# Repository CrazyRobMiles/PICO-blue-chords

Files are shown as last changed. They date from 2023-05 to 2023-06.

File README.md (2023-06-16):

# PICO-blue-chords

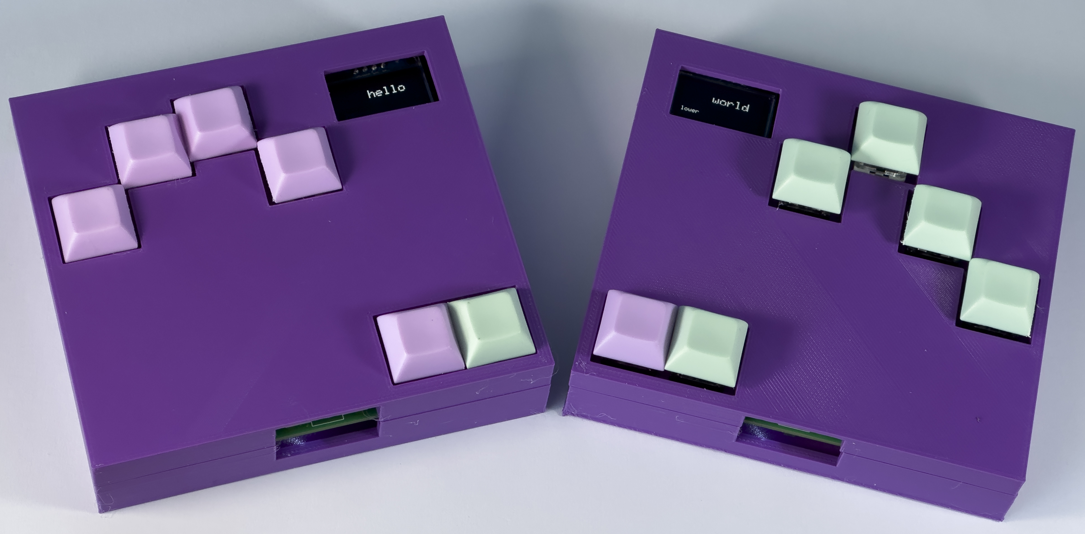
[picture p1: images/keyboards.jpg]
Image of left and right handed versions of the keyboard

This is a chord keyboard that uses the MicroWriter chord system. It uses the Bluetooth to connect and runs on a Raspberry Pi PICO-W. It is described in the HackSpace magazine. 
## Note
This is a work in progress. The software works correctly and the PCB and the case designs are now complete but these updated designs have not been constructed. The author knows of no reason why they won't work, but he didn't know of any reasons why the prototype wouldn't work until he tried to use it...

## Using a chord keyboard
You can find instructions on how to use the keyboard and the chord shapes in the doc folder. 
## Installing the software on your PICO from the UF2 Images
You can install the software by following these steps:
1. Press down the boot button on your PICO-W.
2. Connect your PICO-W to a usb port on your computer. 
3. The PICO-W should show up as a external drive.
4. The UF2 folder holds images for left and right handed use. Drag the left or right handed uf2 file onto the drive. 
5. The PICO-W will reboot running the software.
## Printed Circuit Board Designs
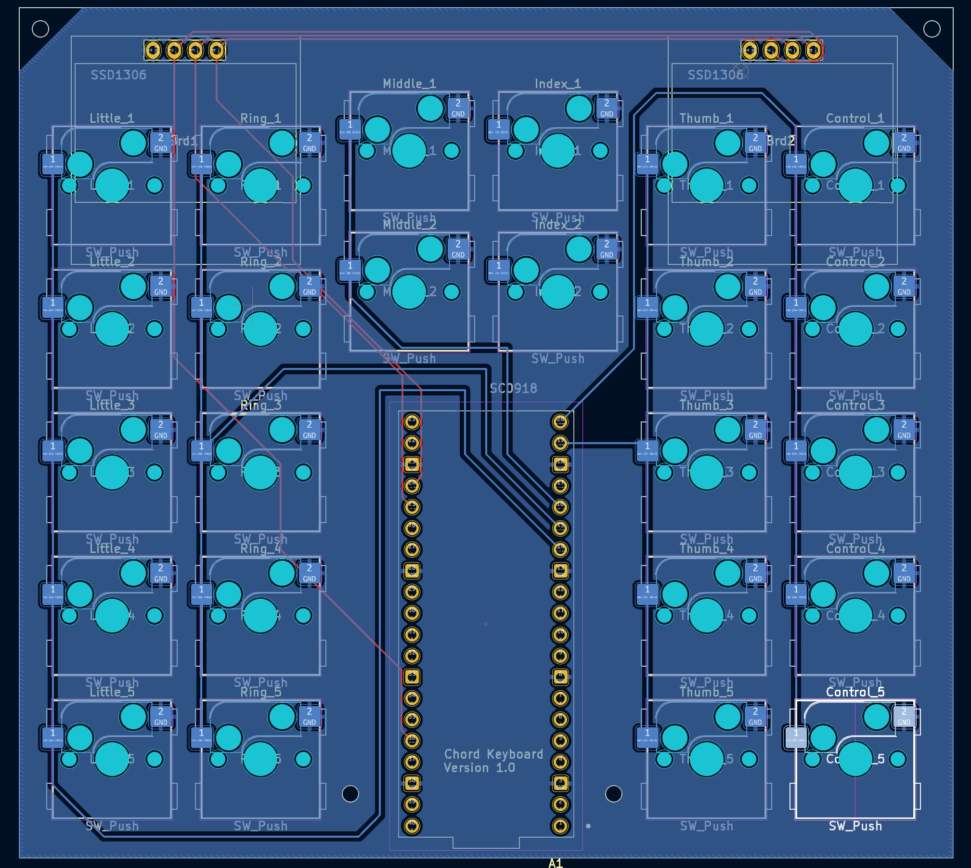
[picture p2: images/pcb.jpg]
Image of the keyboard PCB

The PCB designs are in the folder PICO-blue-chords-pcb. This folder also contains the partsdump.py file which can be used to extract the footprint positions for use in the case design software.
## Case 
To create a custom case design you use the PICO-blue-chords-case-builder.FCMacro macro which is in the cases folder. Load this into FreeCAD and select left or right handed and the specific key positions. The macro contains the following statements:
```
# right handed flag
right_handed = True 
if right_handed:
	keyHoles = [Little_5,Ring_5, Middle_2, Index_1, Thumb_1,Control_2]
	displayHole = Brd2
else:
      keyHoles = [Little_3,Ring_2, Middle_1, Index_2, Thumb_5,Control_5]
      displayHole = Brd1
```
Set the value of right_handed to False if you want a left-handed keyboard. Change the numbers for each key to match the position that you want for that key hole. The higher the number the farther down the keyboard the key hole will be placed. You can see the key numbers on the PCB design above. Run the macro and then export the resulting design as an STL file for printing. 
## Building the code
You use CMAKE to build the application from source. If you load the project with Visual Studio Code, make sure that you have the CMake Tools extension installed. The file CMakeLists.txt is used to create the makefiles for the build. Line 10 of this file sets the path to the SDK:
```
set(PICO_SDK_PATH "C:/Program Files/Raspberry Pi/Pico SDK v1.5.1/pico-sdk")
```
This works on my Windows system. You may need to change this when building the software on your machine. Note that you don't need to build the software yourself to use it. You can just install the image files which will be in the build folder which is created by the build process. 

## Origins
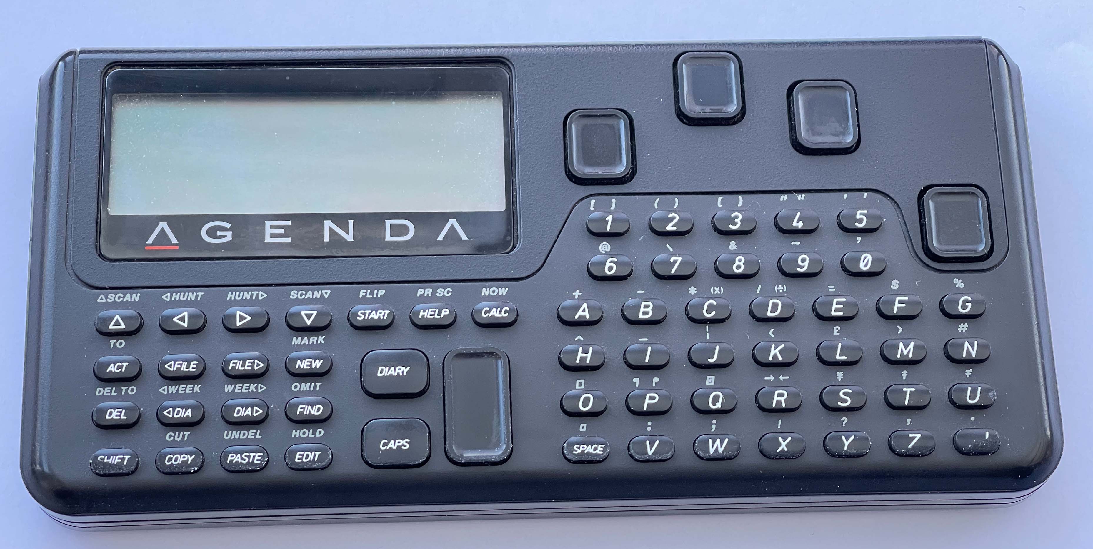
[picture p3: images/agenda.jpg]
Image of Microwriter Agenda

The keyboard is based on the Cykey chord design by Cy Enfield which was used as the basis of the Microwriter and Microwriter AgendA devices developed by him and Chris Rainey. You can find out more about these devices [here](http://www.computinghistory.org.uk/det/5794/Microwriter-MW4/), [here](https://www.microsoft.com/buxtoncollection/detail.aspx?id=5) and [here](https://mindmachine.co.uk/book/A/Inp-Outp/Microwriter01.html). 

If you want to buy an official Microwriter keyboard you can get one [here](https://sites.google.com/site/cykeybellaire/home). 

Have fun!

Rob Miles: [blog](https://www.robmiles.com)

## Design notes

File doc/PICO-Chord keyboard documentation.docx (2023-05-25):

The keyboard can be used in place of a Bluetooth keyboard. Before you use it you must pair it with your device. It will appear as the device “Blue Chord Keyboard xx:xx:xx:xx . You may need to re-pair it after it has been powered down.

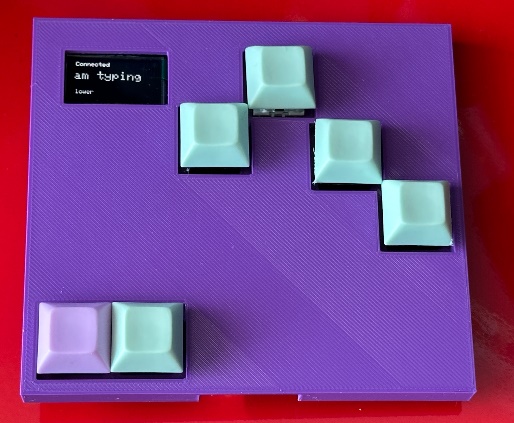
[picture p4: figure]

A right-handed version of the keyboard. The right hand five keys are used to enter chords. The left hand key is used as a control key.

# Typing Text

You type on the keyboard by pressing down "chords". A chord is one or more keys. A character is registered when you release one of the keys in the chord that describes it. Release all the chord keys for character before entering the next one. A map of all the chords is at the end of this document. Text is entered using the five keys underneath the hand shown on the left. The far-left key is the control key.

# Control Key

The control key is used to change the mode of the keyboard. You use it by moving your thumb slightly left to press that key. If you press and release just the control key the keyboard will change from lower case to upper case text entry. Press and release the control key again to return the lower-case text.

## Commands

The control key can be used in conjunction with other letters to enter commands that change the mode of the keyboard and send cursor control commands from the keyboard. The chords for the commands are given at the end of this document. There are three kinds of command. Cursor control, keyboard mode and keyboard functions.

## Cursor control

bak move the cursor left. This sends a keypress that moves the cursor one position left.

del backspace delete. This sends a keypress that deletes the character under the cursor and moves the cursor one space to the left.

## Keyboard mode

The keyboard mode is shown on the bottom of the display screen:

CAPS toggle the caps lock state by pressing the Control key on its own.

num enter numeric mode. The keys will turn green. You can enter numbers using the chords described in the Numbers section of the chord descriptions.

sym enter symbol mode. The keys will turn magenta. You can enter symbols using the chords described in the Symbols part of the chord descriptions.

lower enter lower case text mode. The keys will turn blue and the keyboard will be set to enter lower case text. You use this mode to exit from num or sym mode.

space

[ ] [ ] [ ] [ ]

[ ] [X]

,

[X] [ ] [X] [X]

[ ] [ ]

[X] [X] [X] [ ]

[ ] [ ]

A

[X] [X] [ ] [ ]

[ ] [ ]

B

[ ] [X] [X] [X]

[ ] [ ]

C

[ ] [X] [ ] [ ]

[ ] [X]

D

[X] [X] [ ] [ ]

[ ] [X]

E

[X] [ ] [ ] [ ]

[ ] [ ]

F

[X] [X] [X] [ ]

[ ] [X]

G

[ ] [ ] [X] [X]

[ ] [ ]

H

[ ] [ ] [ ] [X]

[ ] [X]

I

[X] [ ] [ ] [ ]

[ ] [X]

J

[ ] [ ] [X] [X]

[ ] [X]

K

[ ] [ ] [X] [ ]

[ ] [X]

L

[X] [ ] [ ] [X]

[ ] [X]

M

[X] [X] [X] [X]

[ ] [ ]

N

[ ] [X] [X] [ ]

[ ] [ ]

O

[ ] [X] [ ] [ ]

[ ] [ ]

P

[X] [X] [X] [X]

[ ] [X]

Q

[ ] [X] [ ] [X]

[ ] [ ]

R

[X] [ ] [X] [ ]

[ ] [X]

S

[ ] [ ] [X] [ ]

[ ] [ ]

T

[X] [ ] [X] [ ]

[ ] [ ]

U

[ ] [ ] [ ] [X]

[ ] [ ]

V

[X] [ ] [ ] [X]

[ ] [ ]

W

[X] [ ] [X] [X]

[ ] [X]

X

[ ] [X] [X] [X]

[ ] [X]

Y

[ ] [X] [X] [ ]

[ ] [X]

Z

[ ] [X] [ ] [X]

[ ] [X]

,

[X] [ ] [X] [X]

[ ] [ ]

[X] [X] [X] [ ]

[ ] [ ]

0

[ ] [X] [ ] [ ]

[ ] [ ]

1

[ ] [ ] [ ] [ ]

[ ] [X]

2

[X] [ ] [ ] [ ]

[ ] [X]

3

[X] [X] [ ] [ ]

[ ] [X]

4

[X] [X] [X] [ ]

[ ] [X]

5

[X] [X] [X] [X]

[ ] [X]

6

[ ] [ ] [ ] [X]

[ ] [ ]

7

[ ] [ ] [X] [X]

[ ] [ ]

8

[ ] [X] [X] [X]

[ ] [ ]

9

[X] [X] [X] [X]

[ ] [ ]

space

[ ] [ ] [ ] [ ]

[ ] [X]

!

[ ] [X] [X] [X]

[ ] [X]

[ ] [ ] [ ] [X]

[ ] [X]

$

[ ] [ ] [X] [ ]

[ ] [ ]

%

[ ] [X] [ ] [X]

[ ] [X]

&

[X] [ ] [X] [ ]

[ ] [X]

(

[X] [X] [ ] [ ]

[ ] [X]

)

[ ] [X] [X] [X]

[ ] [ ]

*

[X] [ ] [X] [ ]

[ ] [ ]

+

[X] [X] [X] [X]

[ ] [X]

,

[X] [ ] [X] [X]

[ ] [ ]

[ ] [X] [X] [ ]

[ ] [ ]

[X] [X] [X] [ ]

[ ] [ ]

/

[ ] [ ] [X] [ ]

[ ] [X]

:

[X] [ ] [X] [X]

[ ] [X]

;

[ ] [ ] [X] [X]

[ ] [X]

<

[X] [ ] [ ] [ ]

[ ] [X]

=

[X] [ ] [ ] [ ]

[ ] [ ]

>

[ ] [ ] [X] [X]

[ ] [ ]

?

[ ] [X] [X] [ ]

[ ] [X]

@

[X] [X] [ ] [ ]

[ ] [ ]

[

[ ] [X] [ ] [ ]

[ ] [X]

\

[X] [ ] [ ] [X]

[ ] [ ]

]

[ ] [X] [ ] [X]

[ ] [ ]

{

[X] [X] [X] [ ]

[ ] [X]

}

[X] [X] [X] [X]

[ ] [ ]

# Cursor

bak : Cursor left

[ ] [X] [X] [X]

[X] [ ]

del : Backspace

[X] [X] [ ] [ ]

[X] [ ]

# Mode

cap : CAPS

[ ] [ ] [ ] [ ]

[X] [ ]

num : Numeric

[ ] [X] [X] [ ]

[X] [ ]

sym : Symbol

[ ] [ ] [X] [ ]

[X] [ ]

text : lower

[X] [ ] [X] [ ]

[X] [ ]

Rob Miles Version 1.0 May 2023

https://github.com/CrazyRobMiles/PICO-blue-chords

PICO Blue Chords Keyboard

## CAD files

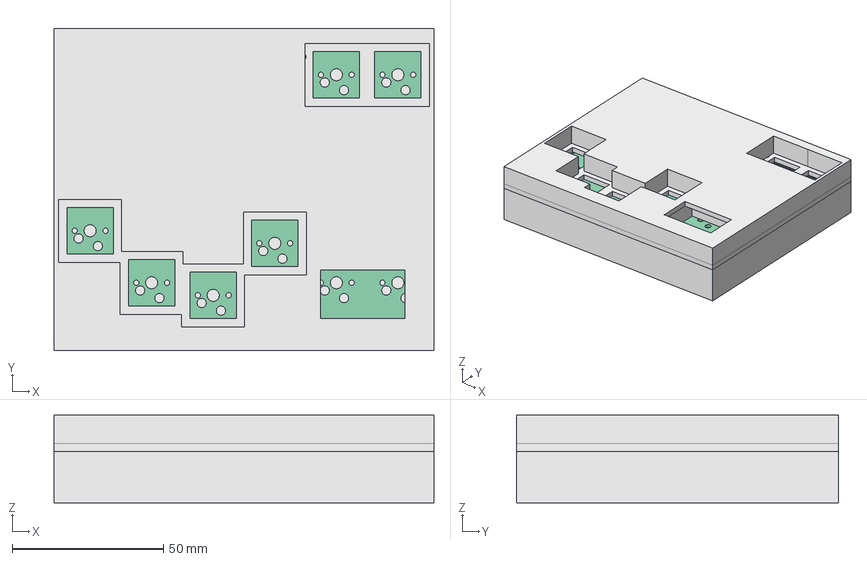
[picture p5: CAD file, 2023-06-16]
case/PCB and case.FCStd
125.5 x 106.5 x 28.9 mm
Pcb_e212

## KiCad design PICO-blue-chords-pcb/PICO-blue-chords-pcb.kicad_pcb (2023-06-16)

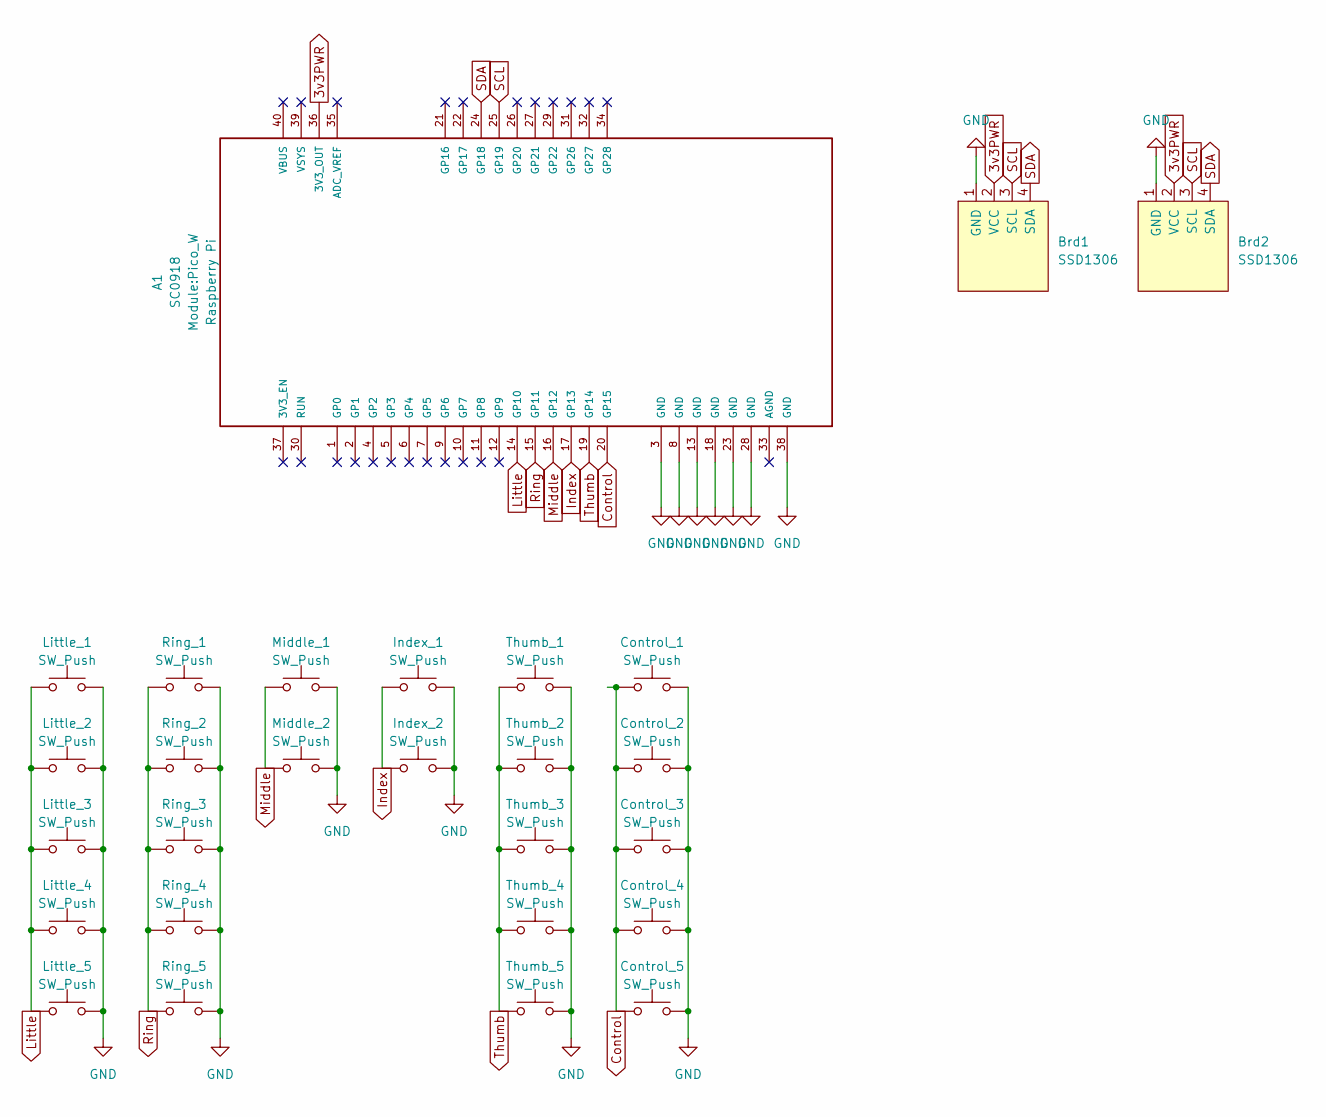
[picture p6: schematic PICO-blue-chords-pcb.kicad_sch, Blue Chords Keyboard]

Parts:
A1: SC0918; Pico_W; PARTREV 1.6
Brd1, Brd2: SSD1306; 128x64OLED
Control_1, Control_2, Control_3, Control_4, Control_5: SW_Push; SW_Hotswap_Kailh_MX
Index_1, Index_2: SW_Push; SW_Hotswap_Kailh_MX
Little_1, Little_2, Little_3, Little_4, Little_5: SW_Push; SW_Hotswap_Kailh_MX
Middle_1, Middle_2: SW_Push; SW_Hotswap_Kailh_MX
Ring_1, Ring_2, Ring_3, Ring_4, Ring_5: SW_Push; SW_Hotswap_Kailh_MX
Thumb_1, Thumb_2, Thumb_3, Thumb_4, Thumb_5: SW_Push; SW_Hotswap_Kailh_MX

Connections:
3v3PWR: A1.36 (3V3_OUT), Brd1.2 (VCC), Brd2.2 (VCC)
Control: A1.20 (GP15), Control_1.1, Control_2.1, Control_3.1, Control_4.1, Control_5.1
GND: A1.3 (GND), A1.8 (GND), A1.13 (GND), A1.18 (GND), A1.23 (GND), A1.28 (GND), A1.38 (GND), Brd1.1 (GND), Brd2.1 (GND), Control_1.2, Control_2.2, Control_3.2, Control_4.2, Control_5.2, Index_1.2, Index_2.2, Little_1.2, Little_2.2, Little_3.2, Little_4.2, Little_5.2, Middle_1.2, Middle_2.2, Ring_1.2, Ring_2.2, Ring_3.2, Ring_4.2, Ring_5.2, Thumb_1.2, Thumb_2.2, Thumb_3.2, Thumb_4.2, Thumb_5.2
Index: A1.17 (GP13), Index_1.1, Index_2.1
Little: A1.14 (GP10), Little_1.1, Little_2.1, Little_3.1, Little_4.1, Little_5.1
Middle: A1.16 (GP12), Middle_1.1, Middle_2.1
Ring: A1.15 (GP11), Ring_1.1, Ring_2.1, Ring_3.1, Ring_4.1, Ring_5.1
SCL: A1.25 (GP19), Brd1.3 (SCL), Brd2.3 (SCL)
SDA: A1.24 (GP18), Brd1.4 (SDA), Brd2.4 (SDA)
Thumb: A1.19 (GP14), Thumb_1.1, Thumb_2.1, Thumb_3.1, Thumb_4.1, Thumb_5.1

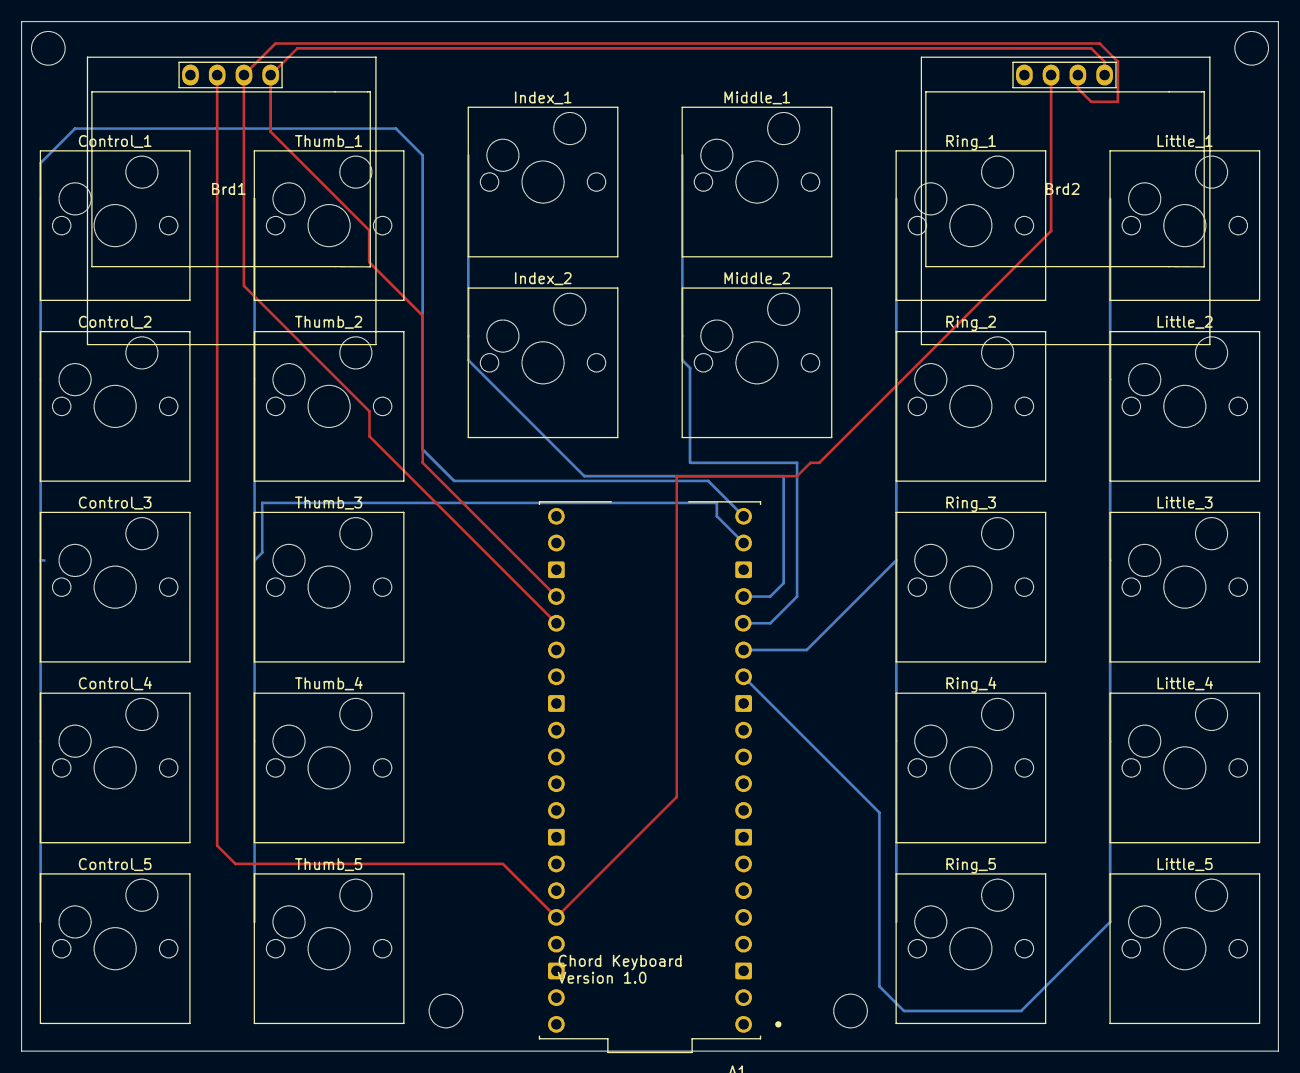
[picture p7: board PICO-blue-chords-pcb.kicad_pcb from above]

Board: 2 copper layers, 119.4 x 97.8 mm, 27 parts (0 on the bottom side), 10 nets.

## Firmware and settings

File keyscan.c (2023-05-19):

#include <stdio.h>
#include "pico/stdlib.h"
#include "hardware/gpio.h"
#include "messages.h"
#include "keyscan.h"

#ifdef LEFT_HANDED_KEYBOARD

#define LITTLE_KEY_GPIO 15
#define RING_KEY_GPIO 14
#define MIDDLE_KEY_GPIO 13
#define INDEX_KEY_GPIO 12
#define THUMB_KEY_GPIO 11
#define CONTROL_KEY_GPIO 10

#else

#define LITTLE_KEY_GPIO 10
#define RING_KEY_GPIO 11
#define MIDDLE_KEY_GPIO 12
#define INDEX_KEY_GPIO 13
#define THUMB_KEY_GPIO 14
#define CONTROL_KEY_GPIO 15

#endif

enum keyboard_states
{
    UPPER_CASE_KEYS,
    LOWER_CASE_KEYS,
    NUMBER_KEYS,
    SYMBOL_KEYS
};

enum keyboard_states keyboard_state;

struct key
{
    int gpio;
    bool state;
    char *name;
    int change_counter;
    int bit_number;
};

struct key keys[] =
    {
        {LITTLE_KEY_GPIO, false, "little key", 0, 0},
        {RING_KEY_GPIO, false, "ring key", 0, 1},
        {MIDDLE_KEY_GPIO, false, "middle key", 0, 2},
        {INDEX_KEY_GPIO, false, "index key", 0, 3},
        {THUMB_KEY_GPIO, false, "thumb", 0, 4},
        {CONTROL_KEY_GPIO, false, "control", 0, 5}};

#define DEBOUNCE_COUNT 1
#define KEY_PRESSED false

struct key_decode
{
    int scan;
    char ch;
};

struct key_decode lower_case_text_decode[] = {
    {12, 'a'},
    {56, 'b'},
    {10, 'c'},
    {14, 'd'},
    {4, 'e'},
    {30, 'f'},
    {48, 'g'},
    {34, 'h'},
    {6, 'i'},
    {50, 'j'},
    {18, 'k'},
    {38, 'l'},
    {60, 'm'},
    {24, 'n'},
    {8, 'o'},
    {62, 'p'},
    {40, 'q'},
    {22, 'r'},
    {16, 's'},
    {20, 't'},
    {32, 'u'},
    {36, 'v'},
    {54, 'w'},
    {58, 'x'},
    {26, 'y'},
    {42, 'z'},
    {2, ' '},
    {52, ','},
    {28, '.'},
    {0, ' '}};

struct key_decode upper_case_text_decode[] = {
    {12, 'A'},
    {56, 'B'},
    {10, 'C'},
    {14, 'D'},
    {4, 'E'},
    {30, 'F'},
    {48, 'G'},
    {34, 'H'},
    {6, 'I'},
    {50, 'J'},
    {18, 'K'},
    {38, 'L'},
    {60, 'M'},
    {24, 'N'},
    {8, 'O'},
    {62, 'P'},
    {40, 'Q'},
    {22, 'R'},
    {16, 'S'},
    {20, 'T'},
    {32, 'U'},
    {36, 'V'},
    {54, 'W'},
    {58, 'X'},
    {26, 'Y'},
    {42, 'Z'},
    {2, ' '},
    {52, ','},
    {28, '.'},
    {0, ' '}};

struct key_decode num_decode[] = {
    {8, '0'},
    {2, '1'},
    {6, '2'},
    {14, '3'},
    {30, '4'},
    {62, '5'},
    {32, '6'},
    {48, '7'},
    {56, '8'},
    {60, '9'},
    {52, '}'},
    {28, '.'},
    {0, ' '}};

struct key_decode sym_decode[] = {
    {2, ' '},
    {52, ','},
    {28, '.'},
    {54, ','},
    {50, ';'},
    {42, '%'},
    {4, '='},
    {22, '&'},
    {14, '('},
    {56, ')'},
    {16, '$'},
    {12, '@'},
    {62, '+'},
    {34, '#'},
    {24, '-'},
    {58, '!'},
    {26, '?'},
    {18, '/'},
    {30, '{'},
    {60, '}'},
    {10, '['},
    {40, ']'},
    {36, '\\'},
    {20, '*'},
    {6, '<'},
    {48, '>'},
    {0, ' '}};

char find_char(char scan, struct key_decode *decode)
{
    while (decode->scan > 0)
    {
        if (scan == decode->scan)
        {
            return decode->ch;
        }
        decode++;
    }
    // return 0 if we reach the end without finding a character
    return 0;
}

char key_bits = 0;
char assembling_bits = false;

int poll_gpio()
{
    char result = 0;

    for (int i = 0; i < sizeof(keys) / sizeof(struct key); i++)
    {

        int bit_mask = 1 << keys[i].bit_number;
        int gpio = keys[i].gpio;
        int in_state = gpio_get(gpio);
        if (keys[i].state == in_state)
        {
            keys[i].change_counter = 0;
        }
        else
        {
            keys[i].change_counter++;
            if (keys[i].change_counter >= DEBOUNCE_COUNT)
            {
                // Got a proper key state change
                // clear the debounce counter
                keys[i].change_counter = 0;
                keys[i].state = in_state;
                if (in_state == KEY_PRESSED)
                {
                    // key has been pressed
                    if (key_bits == 0)
                    {
                        // first press of a key
                        assembling_bits = true;
                    }
                    key_bits = key_bits + bit_mask;
                }
                else
                {
                    // key has been released
                    int bits = key_bits;
                    key_bits = key_bits - bit_mask;
                    if (assembling_bits)
                    {
                        // first key lifted which is part of a character
                        // decode it
                        result = bits;
                        assembling_bits = false;
                    }
                }
            }
        }
    }
    return result;
}

bool old_state;

void set_keyboard_state(enum keyboard_states state)
{

    keyboard_state = state;

    switch (keyboard_state)
    {
    case UPPER_CASE_KEYS:
        display_shift_status("CAPS");
        break;
    case LOWER_CASE_KEYS:
        display_shift_status("lower");
        break;
    case NUMBER_KEYS:
        display_shift_status("NUMB");
        break;
    case SYMBOL_KEYS:
        display_shift_status("SYM");
        break;
    }
}

void toggle_caps_lock()
{
    if (keyboard_state == UPPER_CASE_KEYS)
    {
        set_keyboard_state(LOWER_CASE_KEYS);
    }
    else
    {
        if (keyboard_state == LOWER_CASE_KEYS)
        {
            set_keyboard_state(UPPER_CASE_KEYS);
        }
    }
}

#define CHAR_RETURN '\n'
#define CHAR_ESCAPE 27
#define CHAR_TAB '\t'
#define CHAR_BACKSPACE 0x7f

int scan_keys()
{
    int bits = poll_gpio();

    if (bits == 0)
    {
        return 0;
    }

    char ch = 0;

    // decode the bits into a character
    switch (keyboard_state)
    {
    case UPPER_CASE_KEYS:
        ch = find_char(bits, upper_case_text_decode);
        break;
    case LOWER_CASE_KEYS:
        ch = find_char(bits, lower_case_text_decode);
        break;
    case NUMBER_KEYS:
        ch = find_char(bits, num_decode);
        break;
    case SYMBOL_KEYS:
        ch = find_char(bits, sym_decode);
        break;
    }

    if (ch == 0)
    {
        switch (bits)
        {
        case 1:
            toggle_caps_lock();
            break;
        case 13:
            ch = CHAR_BACKSPACE;
            break;
        case 17:
            set_keyboard_state(SYMBOL_KEYS);
            break;
        case 21:
            set_keyboard_state(LOWER_CASE_KEYS);
            break;
        case 25:
            set_keyboard_state(NUMBER_KEYS);
            break;
        case 44:
            ch = CHAR_RETURN;
            break;
        }
    }

    add_character_to_message(ch);

    return ch;
}
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

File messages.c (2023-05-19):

#include <stdio.h>
#include "ssd1306.h"
#include "image.h"
#include "acme_5_outlines_font.h"
#include "bubblesstandard_font.h"
#include "crackers_font.h"
#include "BMSPA_font.h"

void setup_gpios(void)
{
    i2c_init(i2c1, 400000);
    gpio_set_function(18, GPIO_FUNC_I2C);
    gpio_set_function(19, GPIO_FUNC_I2C);
    gpio_pull_up(18);
    gpio_pull_up(19);
}

#define SLEEPTIME 25

ssd1306_t disp;

#define BUFFER_SIZE 100

char current_message[BUFFER_SIZE];
char bluetooth_status[BUFFER_SIZE];
char shift_status[BUFFER_SIZE];

void render_messages()
{
    ssd1306_clear(&disp);
    ssd1306_draw_string(&disp, 0, 16, 2, current_message);
    ssd1306_draw_string(&disp, 2, 0, 1, bluetooth_status);
    ssd1306_draw_string(&disp, 2, 48, 1, shift_status);
    ssd1306_show(&disp);
}

int message_pos = 0;
#define MESSAGE_LIMIT 8

void display_message(const char *s)
{
    snprintf(current_message, BUFFER_SIZE, s);
    render_messages();
}

void add_character_to_message(char ch)
{
    if(ch<32 || ch>126){
        return;
    }

    if (message_pos < MESSAGE_LIMIT)
    {
        current_message[message_pos] = ch;
        message_pos++;
    }
    else
    {
        for (int i = 0; i < MESSAGE_LIMIT; i++ )
        {
            current_message[i] = current_message[i+1];
        }
        current_message[message_pos] = ch;
    }
    render_messages();
}

void clear_message(){
    for(int i=0;i<BUFFER_SIZE;i++){
        current_message[i] = ' ';
    }
    message_pos=0;
    render_messages();
}

void display_bluetooth_status(const char *s)
{
    snprintf(bluetooth_status, BUFFER_SIZE, s);
    render_messages();
}

void display_shift_status(const char *s)
{
    snprintf(shift_status, BUFFER_SIZE, s);
    render_messages();
}

void init_messages()
{
    setup_gpios();

    disp.external_vcc = false;
    ssd1306_init(&disp, 128, 64, 0x3C, i2c1);
    ssd1306_clear(&disp);
    display_message("");
    display_bluetooth_status("");
    display_shift_status("");
}

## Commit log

2023-05-25 Alpha release
    [PICO-blue-chords-pcb.kicad_pcb, PICO-blue-chords-pcb.kicad_sch, safety.kicad_sch]
2023-06-16 Upgraded to use SDK and added missing PCB tracks.
    [PICO-blue-chords-pcb.kicad_pcb, PICO-blue-chords-pcb.kicad_sch]
2023-06-16 Feature complete release
    [PCB and case.FCStd]
